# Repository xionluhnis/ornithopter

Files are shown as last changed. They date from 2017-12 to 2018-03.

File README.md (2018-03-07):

# Ornithopter with ATMega328p
Ornithopter board, code and more for HTMAA.

* Generic board using ATMega328p with [avrdude](http://savannah.nongnu.org/projects/avrdude) for programming
* Initial control code for wing flapping using two servo motors
* Communication using nRF24 and the [RF24](http://tmrh20.github.io/RF24/) library, slightly modified to work without requiring the Arduino code

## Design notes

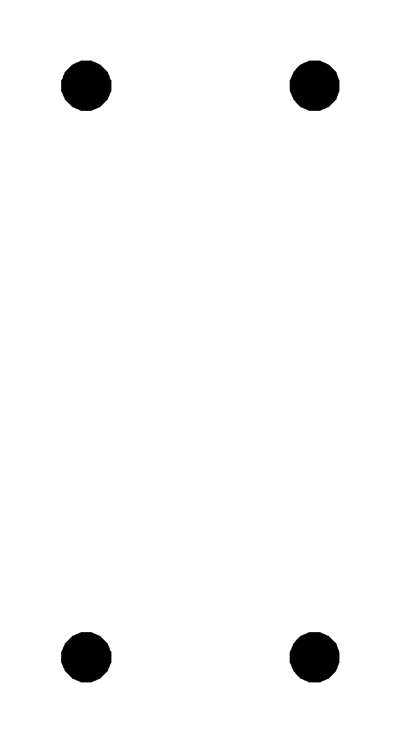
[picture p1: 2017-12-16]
hardware/dcboard/drill2.png

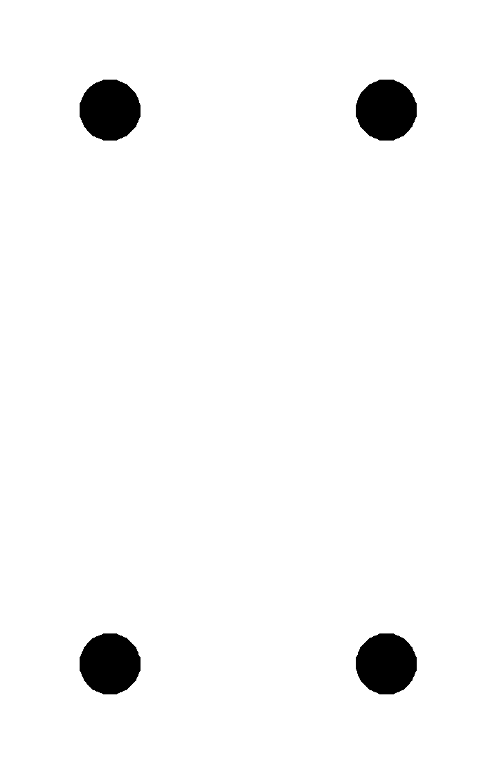
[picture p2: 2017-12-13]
hardware/dcboard/drill.png

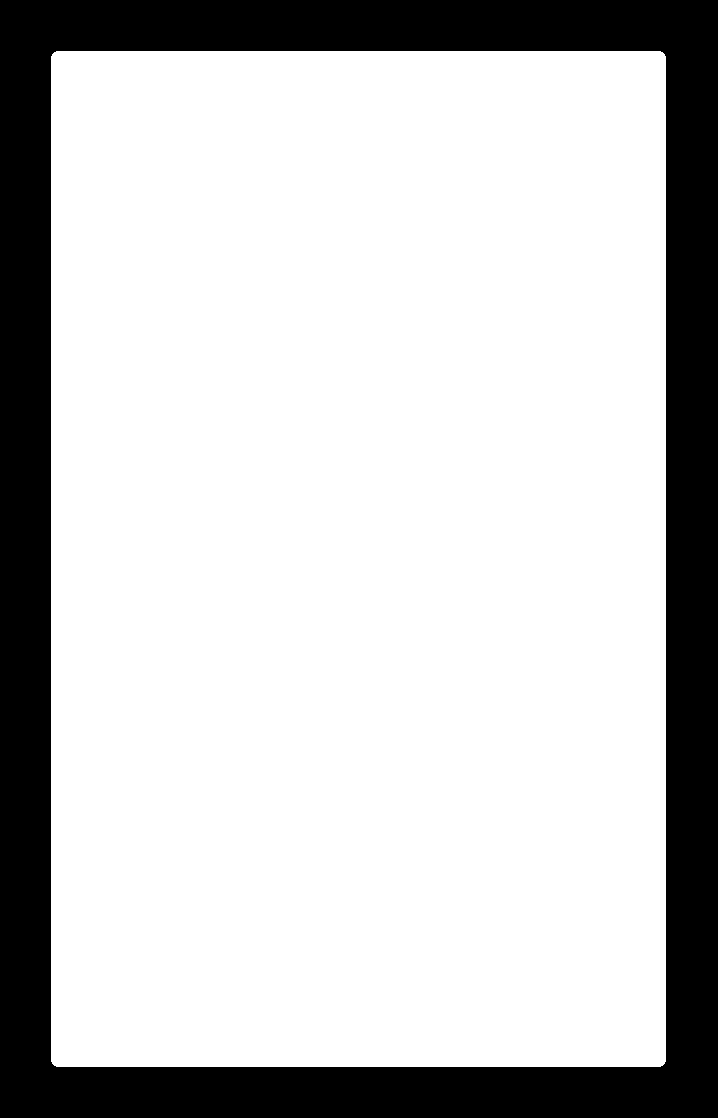
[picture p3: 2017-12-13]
hardware/dcboard/outline.png

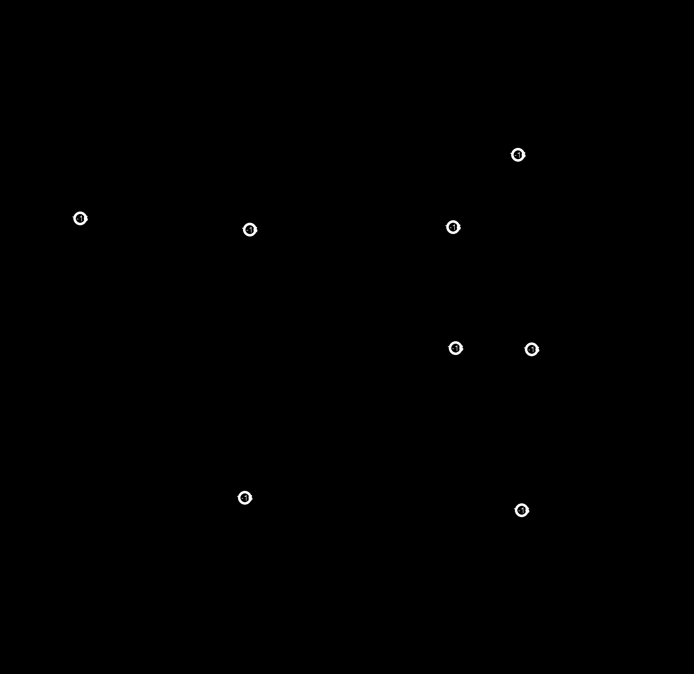
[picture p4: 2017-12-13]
hardware/lightboard/vias.png

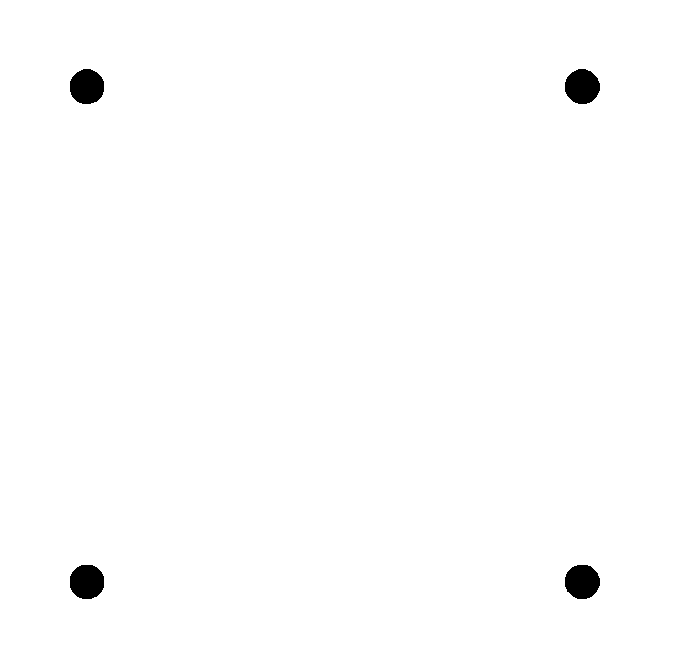
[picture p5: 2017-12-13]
hardware/lightboard/holes.png

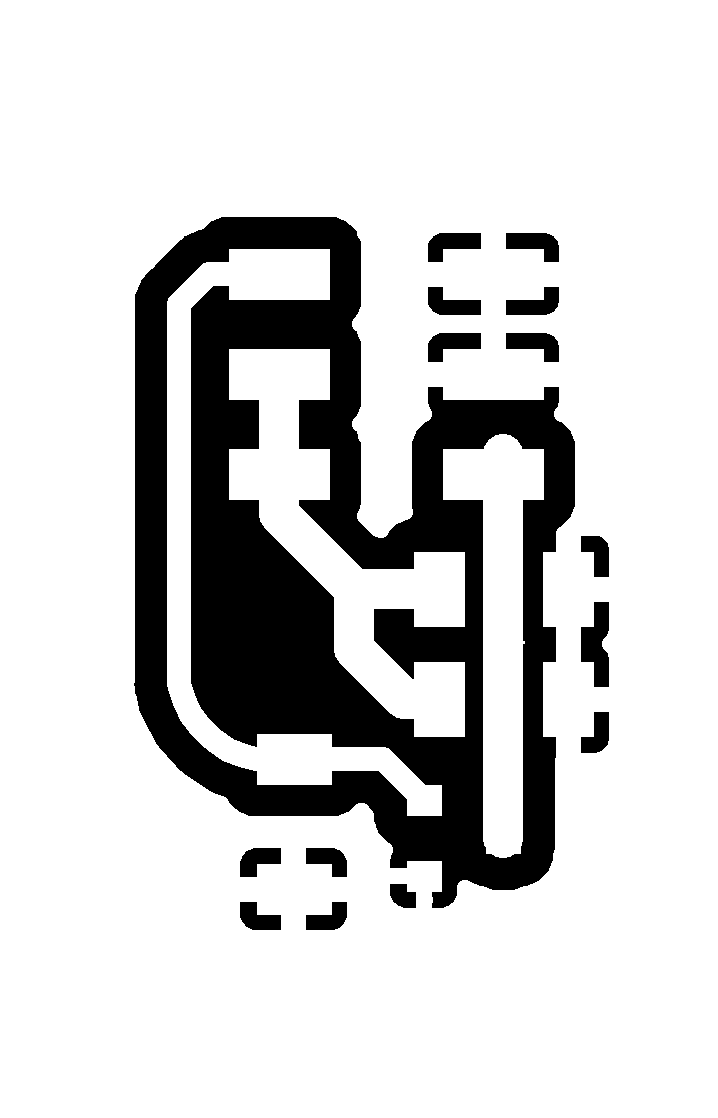
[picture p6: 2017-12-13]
hardware/dcboard/trace.png

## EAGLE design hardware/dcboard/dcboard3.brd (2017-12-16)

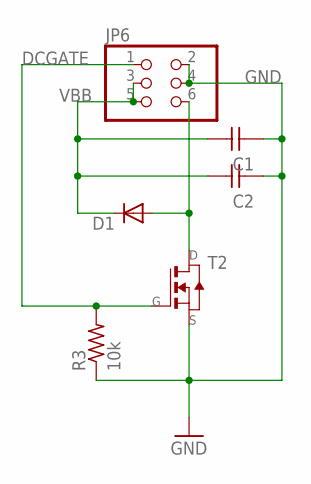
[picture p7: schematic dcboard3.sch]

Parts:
C1, C2: CAP-UNPOLARIZEDFAB; C1206FAB
D1: DIODESOD123; SOD123
JP6: PINHD-2X3-SMD; 2X03SMD
R3: 10k; R1206FAB
T2: NMOSFETTO252; TO252

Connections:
DCGATE: JP6.1, R3.2, T2.1 (G)
GND: C1.1, C2.1, JP6.2, JP6.4, R3.1, T2.2 (S)
unnamed: D1.ANODE (A), JP6.6, T2.3 (D)
VBB: C1.2, C2.2, D1.CATHODE (C), JP6.3, JP6.5

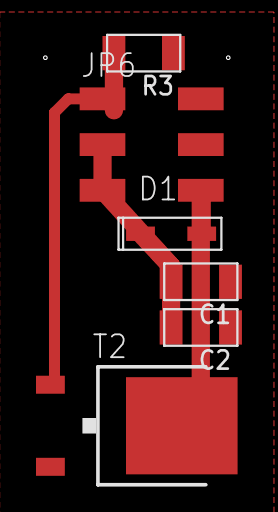
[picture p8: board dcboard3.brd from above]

Board: 2 copper layers, 6 parts (0 on the bottom side), 4 nets.

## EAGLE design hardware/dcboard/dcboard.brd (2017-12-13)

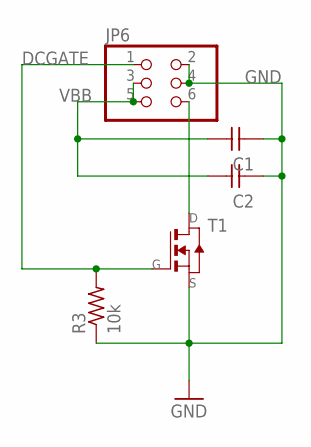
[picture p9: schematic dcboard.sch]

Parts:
C1, C2: CAP-UNPOLARIZEDFAB; C1206FAB
JP6: PINHD-2X3-SMD; 2X03SMD
R3: 10k; R1206FAB
T1: NMOSFETSOT23; SOT-23

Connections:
DCGATE: JP6.1, R3.2, T1.3 (G)
GND: C1.1, C2.1, JP6.2, JP6.4, R3.1, T1.2 (S)
unnamed: JP6.6, T1.1 (D)
VBB: C1.2, C2.2, JP6.3, JP6.5

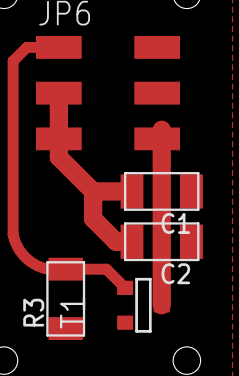
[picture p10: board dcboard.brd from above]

Board: 2 copper layers, 5 parts (0 on the bottom side), 4 nets.

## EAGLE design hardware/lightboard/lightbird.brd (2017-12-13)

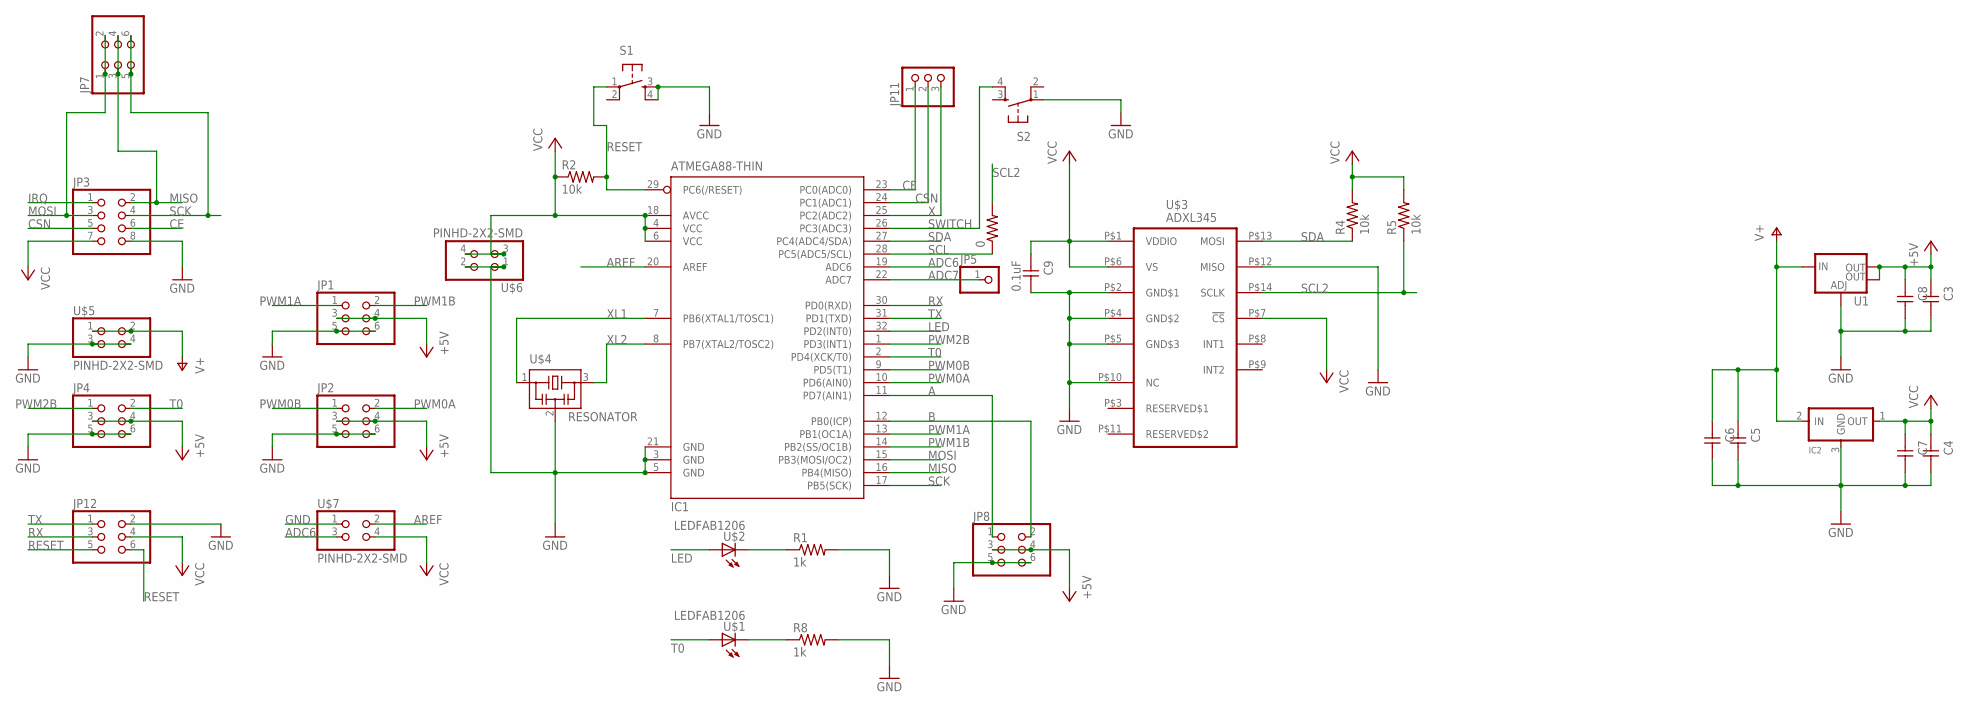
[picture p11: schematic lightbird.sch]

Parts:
0: RES-US1206FAB; R1206FAB
C3, C4, C5, C6, C7, C8: CAP-UNPOLARIZEDFAB; C1206FAB
C9: 0.1uF; C1206FAB
IC1: ATMEGA88-THIN; TQFP32-08THIN
IC2: REGULATORSOT23; SOT23
JP1, JP2, JP4, JP7, JP8, JP12: PINHD-2X3-SMD; 2X03SMD
JP3: PINHD-2X4SMT; 2X04_SMT
JP5: PINHD-1X1; 1X01
JP11: PINHD-1X3; 1X03
R1, R8: 1k; R1206FAB
R2, R4, R5: 10k; R1206FAB
S1, S2: 6MM_SWITCH6MM_SWITCH; 6MM_SWITCH
U1: V_REG_LM1117SOT223; SOT223
U$1, U$2: LEDFAB1206; LED1206FAB
U$3: ADXL345; LGA14
U$4: RESONATOR; EFOBM
U$5, U$6, U$7: PINHD-2X2-SMD; 2X02SMD

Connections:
+5V: C3.1, C8.1, JP1.3, JP1.4, JP2.3, JP2.4, JP4.3, JP4.4, JP8.3, JP8.4, U1.2 (OUT), U1.4 (OUT)
A: IC1.11 (PD7(AIN1)), JP8.1
ADC6: IC1.19 (ADC6), U$7.3
ADC7: IC1.22 (ADC7), JP5.1
AREF: IC1.20 (AREF), U$7.2
B: IC1.12 (PB0(ICP)), JP8.2
CE: IC1.23 (PC0(ADC0)), JP3.6, JP11.1
CSN: IC1.24 (PC1(ADC1)), JP3.5, JP11.2
GND: C3.2, C4.2, C5.2, C6.2, C7.2, C8.2, C9.2, IC1.3 (GND), IC1.5 (GND), IC1.21 (GND), IC2.3 (GND), JP1.5, JP1.6, JP2.5, JP2.6, JP3.8, JP4.5, JP4.6, JP8.5, JP8.6, JP12.2, R1.2, R8.2, S1.3 (S), S1.4 (S1), S2.1, U1.1 (ADJ), U$3.P$2 (GND$1), U$3.P$4 (GND$2), U$3.P$5 (GND$3), U$3.P$10 (NC), U$3.P$12 (MISO), U$4.2, U$5.3, U$5.4, U$6.1, U$6.2, U$7.1
IRQ: JP3.1
LED: IC1.32 (PD2(INT0)), U$2.1 (A)
MISO: IC1.16 (PB4(MISO)), JP3.2, JP7.3, JP7.4
MOSI: IC1.15 (PB3(MOSI/OC2)), JP3.3, JP7.1, JP7.2
unnamed: R1.1, U$2.2 (C)
unnamed: R8.1, U$1.2 (C)
PWM0A: IC1.10 (PD6(AIN0)), JP2.2
PWM0B: IC1.9 (PD5(T1)), JP2.1
PWM1A: IC1.13 (PB1(OC1A)), JP1.1
PWM1B: IC1.14 (PB2(SS/OC1B)), JP1.2
PWM2B: IC1.1 (PD3(INT1)), JP4.1
RESET: IC1.29 (PC6(/RESET)), JP12.5, JP12.6, R2.2, S1.1
RX: IC1.30 (PD0(RXD)), JP12.3
SCK: IC1.17 (PB5(SCK)), JP3.4, JP7.5, JP7.6
SCL: 0.1, IC1.28 (PC5(ADC5/SCL))
SCL2: 0.2, R5.1, U$3.P$14 (SCLK)
SDA: IC1.27 (PC4(ADC4/SDA)), R4.1, U$3.P$13 (MOSI)
SWITCH: IC1.26 (PC3(ADC3)), S2.4 (S1)
T0: IC1.2 (PD4(XCK/T0)), JP4.2, U$1.1 (A)
TX: IC1.31 (PD1(TXD)), JP12.1
V+: C5.1, C6.1, IC2.2 (IN), U1.3 (IN), U$5.1, U$5.2
VCC: C4.1, C7.1, C9.1, IC1.4 (VCC), IC1.6 (VCC), IC1.18 (AVCC), IC2.1 (OUT), JP3.7, JP12.4, R2.1, R4.2, R5.2, U$3.P$1 (VDDIO), U$3.P$6 (VS), U$3.P$7 (!CS), U$6.3, U$6.4, U$7.4
X: IC1.25 (PC2(ADC2)), JP11.3
XL1: IC1.7 (PB6(XTAL1/TOSC1)), U$4.1
XL2: IC1.8 (PB7(XTAL2/TOSC2)), U$4.3

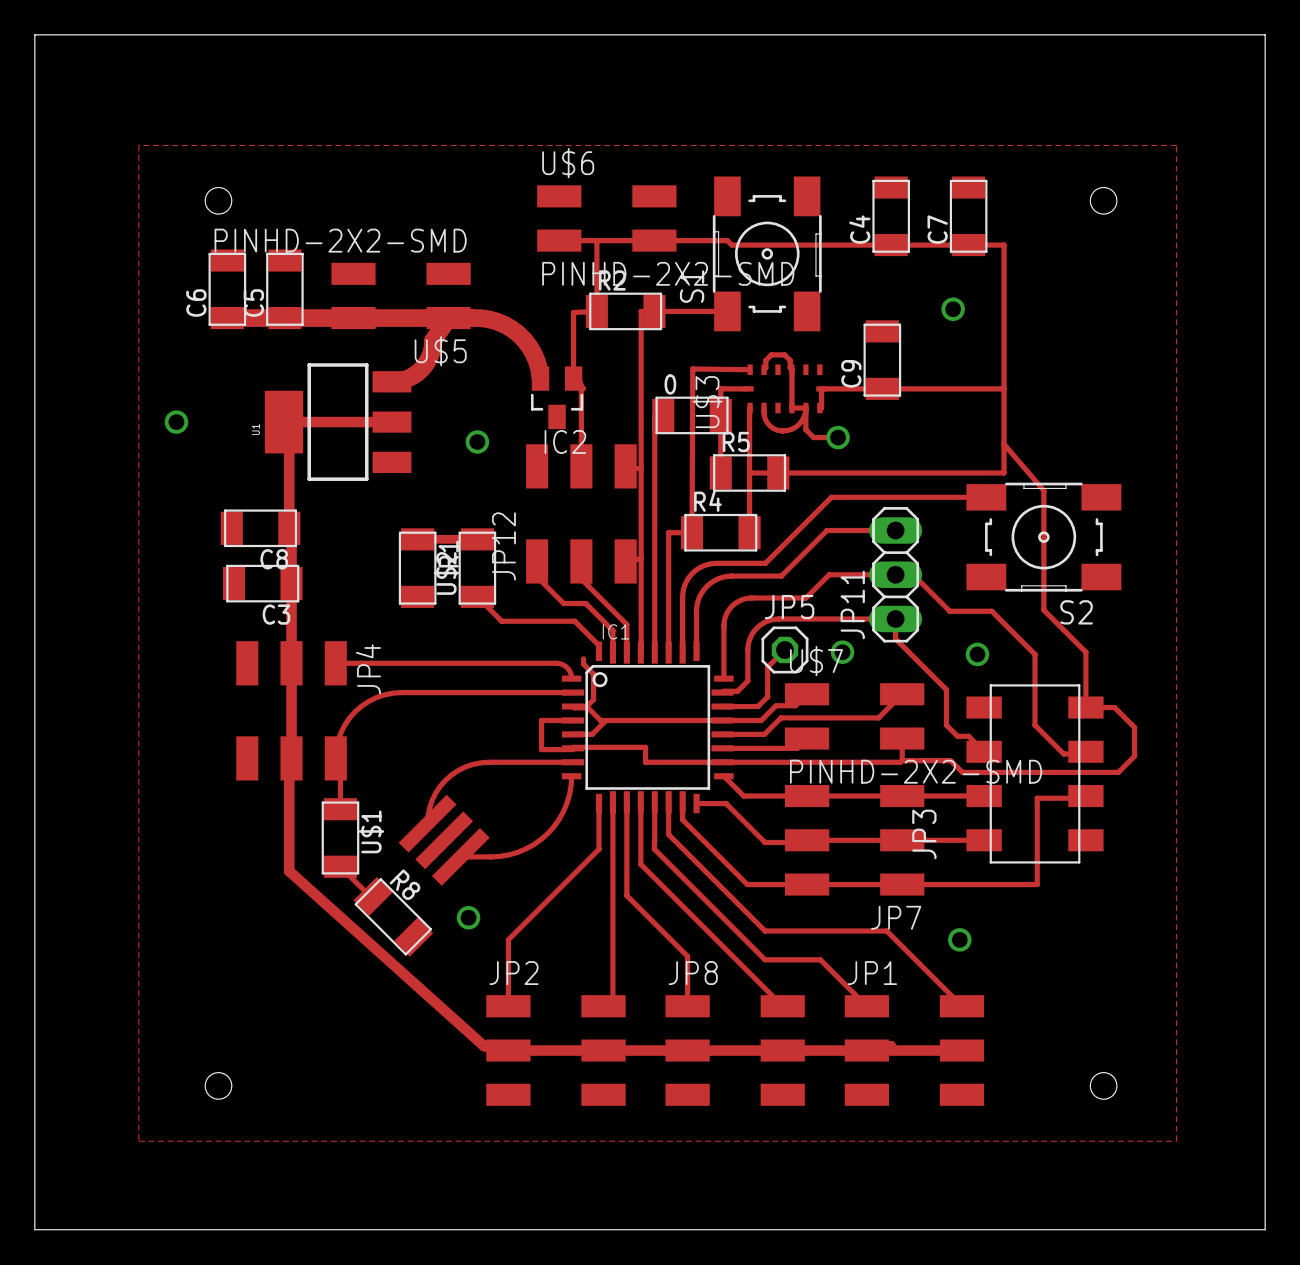
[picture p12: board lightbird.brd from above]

Board: 2 copper layers, 70.6 x 68.6 mm, 34 parts (0 on the bottom side), 33 nets.

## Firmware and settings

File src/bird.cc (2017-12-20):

// Alexandre Kaspar <akaspar@mit.edu>

#include <avr/io.h>
#include <util/delay.h>
#include <stdint.h>

// angle definition for wings
#ifndef TOP_ANGLE
#define TOP_ANGLE 40
#endif
#ifndef BOT_ANGLE
#define BOT_ANGLE 20
#endif
// PWM conversion
// 90deg  = 1ms   = 1250
// 0deg   = 1.5ms = 1875
// -90deg = 2ms   = 2500
#define PWM_MAX 2500UL
#define PWM_MID 1875UL
#define PWM_MIN 1250UL
// our angles
#define PWM_TOP (PWM_MID + (PWM_MAX - PWM_MID) * TOP_ANGLE / 90UL)
#define PWM_BOT (PWM_MID - (PWM_MID - PWM_MIN) * BOT_ANGLE / 90UL)
#define PWM_INV(a) (PWM_MIN + PWM_MAX - a)

// maximum allowed consecutive timeouts before going into landing
#ifndef MAX_TIMEOUTS
#define MAX_TIMEOUTS -1
#endif
// timeout in milliseconds
#ifndef RADIO_TIMEOUT
#define RADIO_TIMEOUT 100
#endif
// radio poll every so often (milliseconds)
#ifndef RADIO_POLLING_PERIOD
#define RADIO_POLLING_PERIOD 1000 
#endif

#ifndef WIRED

// control from serial board
#define RADIO_NUM 1
#include "radio.h"

#endif

#include "command.h"
#include "control.h"
#include "pwm.h"
#include "time.h"
#include "usart.h"

void toggle_led(){
  static char state = 0;
  DDRD |= (1 << PD2);
  if(state)
    PORTD |= (1 << PD2);
  else
    PORTD &= ~(1 << PD2);
  state = !state;
}

// global variables
Control controller;
unsigned long maxFrequency = 10UL; // 10 toggles per second
bool running = false;
// counters / timers
unsigned long counter = 0;
uint8_t numTimeouts = 0;

bool check_run_switch();
void update_wings();
void update_tail();
void radio_input();

int main(void) {

  clock_init(); // /1 prescaler
#ifdef WIRED
  USART_init();
  USART_send("Bird initializing.\r\n");
#else
  radio_init();
#endif
  pwm0_init();
  pwm1_init();
  pwm2_init();
  // and finally the time system
  time_init();

  // switch => pullup
  PORTC |= (1 << PC3);
  DDRD |= (1 << PD7); // trigger signal

#ifdef WIRED
  USART_send("\r\nDDRB=");
  USART_sendNumber(DDRB, 2);
  USART_send("\r\nDDRC=");
  USART_sendNumber(DDRC, 2);
  USART_send("\r\nDDRD=");
  USART_sendNumber(DDRD, 2);
  USART_send("\r\n\r\nPORTB=");
  USART_sendNumber(PORTB, 2);
  USART_send("\r\nPORTC=");
  USART_sendNumber(PORTC, 2);
  USART_send("\r\nPORTD=");
  USART_sendNumber(PORTD, 2);
  USART_send("\r\n");
#endif

  // LOOP
  while(1){
    // USART_sendNumber(millis());
    // USART_send("\r\n");

    // switches
    if(check_run_switch())
      running = !running;

    // update speed
    update_wings();

    // update orientation
    update_tail();

#ifdef WIRED
    if(USART_ready_to_read()){
      unsigned char c = USART_read();
      USART_send("Input: ");
      USART_send(c);
      USART_send("\r\n");
      Command cmd = 0;
      if(controller.input(c, &cmd)){
        USART_send("Command: ");
        USART_sendNumber(cmd, 16);
        USART_send("\r\n");
      }
    }

#else
    radio_input();
#endif

    toggle_led();
    ++counter;

#ifdef WIRED
    if(counter % 10000 == 0){
      USART_send("m=");
      USART_sendNumber(millis());
      USART_send("\r\n");
    }
#endif

    // second led
    if(seconds() % 2)
      PORTD |= (1 << PD4);
    else
      PORTD &= ~(1 << PD4);
  }
  
  return 0;
}


bool check_run_switch(){
  static unsigned long lastSwitch = 0;
  bool trigger = false;
  bool runSwitch = PINC & (1 << PC3); // is the switch being pressed?
  if(!runSwitch){
    unsigned long now = millis();
    trigger = now > lastSwitch + 1000UL;
    lastSwitch = now; // so we can press as long as we want (and only count after release)
  }
  return trigger;
}

void update_wings(){
  static unsigned long lastToggle = 0;
  static enum {
    TOP,
    MIDDLE,
    BOTTOM
  } wingState = MIDDLE;
  // cases
  if(!running || (MAX_TIMEOUTS >= 0 && numTimeouts > MAX_TIMEOUTS)){
    // if not active, stay in mid position
    wingState = MIDDLE;
    OCR1A = PWM_MID;
    OCR1B = PWM_MID;
  } else if(!controller.speed){
    // special case, we go at the top angle
    wingState = TOP;
    OCR1A = PWM_TOP;
    OCR1B = PWM_BOT;
  } else {
    unsigned long now = millis();
    // full speed (100) => 10Hz toggle cycle (1 up + 1 down)
    unsigned long deltaThreshold = 1000UL * maxFrequency / ((unsigned long)controller.speed) / 2UL;
    // Note: / 2 is because we need two toggles (1 up + 1 down)
    if(now  >= lastToggle + deltaThreshold){
      if(wingState == TOP)
        wingState = BOTTOM;
      else
        wingState = TOP;
      lastToggle = now;
      // change PWM
      if(wingState == BOTTOM) {
        OCR1A = PWM_BOT;
        OCR1B = PWM_TOP;
      } else {
        OCR1A = PWM_TOP;
        OCR1B = PWM_BOT;
      }
    }
  }
}

void update_tail(){
  // TODO implement this!
}

void radio_input(){
  static unsigned long lastRadio = 0;
  unsigned long now = millis();

  // only poll every so often
  // TODO the polling should depend on speed
  // TODO communication should be done with interrupts, not
  if(now < lastRadio + RADIO_POLLING_PERIOD)
    return;
  else
    lastRadio = now;

  // process input from user
  bool timeout = false;
  while ( ! radio.available() ){
    if(millis() > now + RADIO_TIMEOUT){
      timeout = true;
      break;
    }
  }
  if ( timeout ){
#if MAX_TIMEOUTS == -1
    return; // we just skip this time
#endif
    // If it times out too many times, we stop the bird by precaution
    // Note: do not let count overflow (else the bird may be in an odd state)
    if(numTimeouts < 255)
      ++numTimeouts;
  }else{
    // reset timeout counter
    numTimeouts = 0;

    // get radio command
    Command response = 0;
    radio.read( &response, sizeof(Command) );

    CommandType what = get_type(response);
    union {
      uint8_t u;
      int8_t  s;
    } data;
    data.u = get_data(response);
    switch(what){

      case Stop:
        if(data.u == 0xFE)
          controller.reset();
        else
          controller.stop();
        break;

      case SetDirection:
        controller.direction = data.s;
        break;

      case SetSpeed:
        controller.speed = data.u;
        break;

      case Trigger:
        // different types of triggers
        switch(data.u){
          case 0x00:
            running = !running;
            break;
          
          case 0x01: {
              static bool triggered = false;
              triggered = !triggered;
              if(triggered)
                PORTD |= (1 << PD7);
              else
                PORTD &= ~(1 << PD7);
            } break;

          default:
            break;
        }
        break;

      default:
#ifdef WIRED
        // this actualy never gets reached right now
        USART_send("Unsupported command: ");
        USART_sendNumber(static_cast<uint8_t>(what), 16);
        USART_send("\r\n");
#endif
        break;
    }
  }

}

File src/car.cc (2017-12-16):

// Alexandre Kaspar <akaspar@mit.edu>

#include <avr/io.h>
#include <util/delay.h>
#include <stdint.h>

#define RADIO_NUM 1

#include "control.h"
#include "pwm.h"
#include "radio.h"
#include "time.h"
#include "usart.h"

void toggle_led(){
  static char state = 0;
  DDRD |= (1 << PD2);
  if(state)
    PORTD |= (1 << PD2);
  else
    PORTD &= ~(1 << PD2);
  state = !state;
}

Control controller;

int main(void) {

  clock_init();
  USART_init();
  radio_init();
  pwm1_init();

  // variant of PWM (not to 25000)
  ICR1 = 10000;

  uint8_t counter = 0;
  // LOOP
  while(1){

    // update speed and orientation
    uint16_t left = 0, right = 0;
    if(controller.direction == 0){
      left  = 100 * controller.speed;
      right = 100 * controller.speed;
    } else if(controller.direction < 0){
      left  = 100 * controller.speed;
      right = (100 + controller.direction) * controller.speed;
    } else {
      left  = (100 - controller.direction) * controller.speed;
      right = 100 * controller.speed;
    }
    OCR1A = left;
    OCR1B = right;

    // process input from user
    bool timeout = false;
    uint16_t count = 0;
    while ( ! radio.available() ){
      ++count;
      if(count > 2000){
        timeout = true;
        break;
      }
    }
    if ( timeout ){
      USART_send("Response timed out.\r\n");
    }else{
      Command response = 0;
      radio.read( &response, sizeof(Command) );

      CommandType what = get_type(response);
      union {
        uint8_t u;
        int8_t  s;
      } data;
      data.u = get_data(response);
      switch(what){

        case Stop:
          if(data.u == 0xFE)
            controller.reset();
          else
            controller.stop();
          break;

        case SetDirection:
          controller.direction = data.s;
          break;

        case SetSpeed:
          controller.speed = data.u;
          break;

        default:
          USART_send("Unsupported command: ");
          USART_sendNumber(static_cast<uint8_t>(what), 16);
          USART_send("\r\n");
          break;
      }
    }

    toggle_led();
    ++counter;
  }
  
  return 0;
}

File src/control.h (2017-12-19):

// Alexandre Kaspar <akaspar@mit.edu>
#pragma once

#include <stdint.h>
#include "command.h"

struct Control {
  uint8_t speed;
  int8_t  direction;
  Control() : speed(0), direction(0) {}

  inline bool left(){
    if(direction > -100)
      direction -= 1;
    else
      return false;
    return true;
  }

  inline bool right(){
    if(direction < 100)
      direction += 1;
    else
      return false;
    return true;
  }

  inline bool faster(){
    if(speed < 100)
      speed += 1;
    else
      return false;
    return true;
  }
  
  inline bool slower(){
    if(speed > 0)
      speed -= 1;
    else
      return false;
    return true;
  }

  inline void stop(){
    speed = 0;
  }

  inline void reset(){
    speed = 0;
    direction = 0;
  }

  bool input(unsigned char c, Command* output = 0){
    Command cmd = 0;
    switch(c){
      case 'a':
        if(slower())
          cmd = make_command(SetSpeed, speed);
        break;

      case 's':
        if(left())
          cmd = make_command(SetDirection, direction);
        break;
  
      case 'd':
        if(faster())
          cmd = make_command(SetSpeed, speed);
        break;
      
      case 'f':
        if(right())
          cmd = make_command(SetDirection, direction);
        break;
  
      case '0':
        speed = 100;
        cmd = make_command(SetSpeed, speed);
        break;
      case '1':
      case '2':
      case '3':
      case '4':
      case '5':
      case '6':
      case '7':
      case '8':
      case '9':
        speed = (c - '0') * 10;
        cmd = make_command(SetSpeed, speed);
        break;
  
      case '>':
        direction = 100;
        cmd = make_command(SetDirection, direction);
        break;
  
      case '<':
        direction = -100;
        cmd = make_command(SetDirection, direction);
        break;
  
      case ' ':
        stop();
        cmd = make_command(Stop, 0xFE);
        break;
  
      case 'q':
        reset();
        cmd = make_command(Stop, 0xFF);
        break;

        // trigger 0x00 => switch first button (running state)
      case 't':
        cmd = make_command(Trigger, 0x00);
        break;
        // trigger 0x01 => pull trigger action (e.g. pooping machine)
      case 'T':
        cmd = make_command(Trigger, 0x01);
        break;
  
      default:
        return false;
    }
    if(output)
      *output = cmd;
    return true;
  }
};

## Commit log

2017-12-09 Added libraries and board files: - Eagle files and SRM20 pngs for Mods - Arduino cores and libs sources - DigitalIO for software IO - RF24 for communicating over nRF24
    [bird.brd, bird.sch]
2017-12-09 Added led example to debug timing and fuses, changed Makefile to be more generic
2017-12-10 Wing servo example
2017-12-10 WIP servos with counter0
2017-12-10 Working third servo
2017-12-10 Added 4th working servo
2017-12-10 Cleaned servo example (no need for serial here)
2017-12-10 Base of accelerometer test
2017-12-11 Accelerometer example output for web UI
2017-12-11 DC motor example
2017-12-11 Better frequency for dc motor
2017-12-12 More reasonable wait time for LED
2017-12-13 Remove DigialIO since we don't need software implementations, updated bird board to newer version
    [bird.brd, bird.sch]
2017-12-13 New boards
    [dcboard.brd, dcboard.sch, lightbird.brd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]
2017-12-13 Traces for dcboard
2017-12-16 New dcboard with bigger mosfet
    [dcboard2.brd, dcboard2.sch]
2017-12-16 New dcboard with flyback diode
    [dcboard3.brd, dcboard3.sch]
2017-12-17 New time management, new control and serial reformatting, basic bird with wing flapping mechanism
2017-12-17 New bird logic, PWM working, but flapping buggy
    [bird.cc, control.h, usart.h]
2017-12-17 Working wing flapping
2017-12-19 New bird code to use RF input, and treating timeouts with milliseconds now
